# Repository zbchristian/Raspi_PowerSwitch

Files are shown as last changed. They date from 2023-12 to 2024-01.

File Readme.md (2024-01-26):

Power Switch HAT for Raspberry Pi based on Arduino Tiny
=======================================================
Per default the Raspberry Pi is powered via the USB port, but no power switch exists for a controlled shutdown.

This device connects to the GPIO and power pins of the extension port.

An Arduino Tiny (Digispark) controls the 5V supply voltage via an MOSFET switch (up to 3A).  
In addition the Arduino 
 - reads the status of the Raspberry Pi on `GPIO 27`. Pulled low while the Raspberry Pi is running, 
 - sets the shutdown request on `GPIO 17` in case the button is pressed, 
 - disconnects the 5V supply from the Raspberry Pi after a predefined timeout. This allows for a controlled shutdown and avoids a possible corruption of the SD-card. 

The device can be powered by a 5V supply, or a DC-DC converter can be added to allow the powering directly from a 12V (or higher) supply (e.g. car battery).
The Arduino is supplied by a 3.3V regulator on the board. This ensures, that the signals of the Arduino and the Raspberry Pi are compatible.

The default power button is a touch button connected via a 1MOhm resistor to Port 4 and sensed via Port 2 of the ATTINY85.
A standard button can be connected to Port 4 as well, but requires to adapt the code.

This device has been developped for the powering of a Raspberry Pi 3a used as Wireless access point (installed is [RaspAP](https://raspap.com/) ) in a very flat case. The Raspberry Pi 
is used in a Camper Van to connect to camp ground wireless networks or LTE/4G. The device is powered in this case by 12V.   

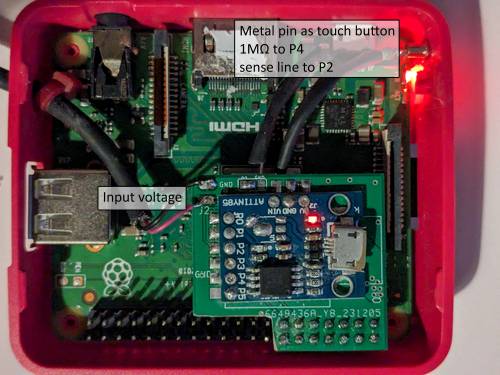
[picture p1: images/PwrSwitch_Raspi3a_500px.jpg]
Prototype Prototype of the Power Switch Raspberry Pi 3a
  
*Power switch installed on a Raspberry Pi 3a, including a touch button (metal pin)*

The power required by the device, when the Raspberry Pi is switched off, is about 20mW (ca. 1.5mA@12V).

Required Hardware Components
-------------------
 - Arduino Tiny - Digispark board. The version with the micro USB port is preferred. This allows to program the board while soldered to the PCB.
 - DC-DC converter in case the the input voltage is higher than 5V.
 - PCB and the required components (SMD components and a pin header)
 - MOSFET transistor 
   - Suitable types: FDN360P, TMS2305, DMT3098 (package: SOT-23). All allow to switch up to 2A continuously, which should still be fine for a Raspberry Pi 4.
   - For higher currents an IRF9310 (up to 16A) could be used, but this comes in a different package (SO-8) and the layout has to be changed accordingly.

Software
--------
The Arduino IDE is used for the programming of the Arduino Tiny. See the header of the program file for more details of the program flow.  
The package `CapacitiveSensor` is required, if the above mentioned touch button is used.

On the Raspberry Pi side, you need to add the following lines to `/boot/config.txt`
````
# Request shutdown by setting GPIO 17 to HIGH
dtoverlay=gpio-shutdown,gpio_pin=17,active_low=0,gpio_pull=down
# GPIO 27 flags the shutdown of the system
gpio=27=op,dl
````

Board Design
------------
Schematic and board design are available in the Autodesk EAGLE format. The library file contains the non-standard components (Arduino Tiny, DC-DC converter). Gerber files, Bill of material and placement files are available as well.

The board connects to the first 14 pins of the extension port of the Raspberry Pi via a pin header. The header connector is installed to the bottom of the board. A low profile connector 
is recommended. For the Raspberry Pi 3a in its default case, the pins had to be shortened a bit and a header with a height of only 8.6mm has been used.  

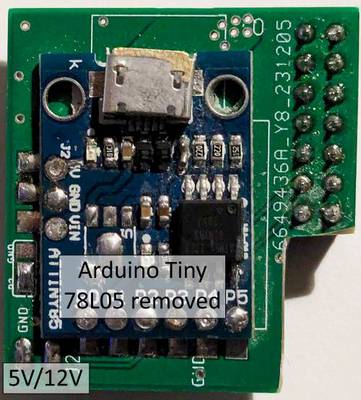
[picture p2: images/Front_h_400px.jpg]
Prototype frontside of the Raspberry Pi Power Switch
  
*Arduino Tiny soldered to the Power Switch board*

The design of the board is somewhat special, because a very flat layout is needed to fit into a standard case. 
Therefore the Arduino Tiny is soldered to large SMD pads. This is not difficult, but requires some soldering experience. It might help to solder a solid wire (0.4mm) to the through holes of the 
Arduino Tiny, bend the wires by 90° to the outside, cut to length and solder the ends of the wires to the SMD pads.  
Before soldering, add an isolating tape to the bottom of the Arduino to avoid shorts. 

On the bottom side of the board a solder jumper sets the source of the power. A closed jumper connects the input voltage from the pin header directly to the Raspberry Pi and the 
on board regulator. For higher voltages, e.g. 12V from a car battery, the jumper should be left open and a mini DC-DC converter is soldered to the SMD pads on the bottom side. The output voltage of the DC-DC converter
should be set to 5V. Again add an isolating tape to the bottom of the DC-DC converter to avoid shorts. 

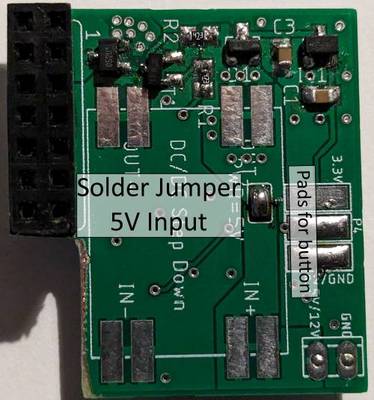
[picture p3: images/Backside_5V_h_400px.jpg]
Prototype Power switch for 5V input voltage

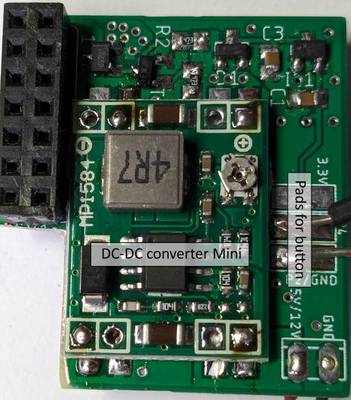
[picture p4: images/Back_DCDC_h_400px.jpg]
Prototype Power switch for 12V input voltage utilizing a DC-DC converter mini
  
*Bottom side of the Power Switch: left side for 5V input voltage with the solder jumper closed. On the right side the DC-DC converter is installed for a higher voltage*

On the bottom side you find in addition 3 solder pads to connect a button. One of the pads carries either the signal of Port 2 or ground. This can be selected by the solder jumper on the top.
 - Passive button: connect to Port 4 and the P2/GND pad and select GND with the solder jumper on the top.
 - Software based touch button: connect to P4 and P2 (select P2 with the solder jumper on top).
 - Hardware touch button: signal connected to P4. Powering by 3.3V and GND pad.

The software based touch button is implemented in the code. The other options require an adaption of the code.  

Quiescent Power Consumption
--------------------------
The Arduino Tiny will draw up to 10mA when powered by the onboard 5V regulator (78X05). This is mainly due to the quiescent current of the regulator itself , the power LED 
and the 1.5kOhm pull-up resistor connected to port 3 of the ATTINY85 (needed for the USB programming). The ATTINY85 with reduced frequency of about 1MHz
utilizes only a few hundred micro Amps. 

Reduce the required power by
 - run the ATTINY85 at a low frequency (e.g. 1MHz)
 - use an external 3.3V regulator with low quiescent current (here MCP1703). Remove the 78X05 from the board (might not be necessary).
 - either remove the power LED, or change at least the series resistor from 1kOhm to 10kOhm
 - remove the LED attached to Port 1, or increase the series resistor to 10kOhm
 - disconnect the 1.5kOhm resistor from the power rail of the ATTINY85 and connect it to the USB 5V line (USB connector side of the corresponding Schottky diode).

For a 5V powered system, this should bring the qiescent current down well below 1mA at 5V.
With the installed DC-DC converter the current stays at about 1.5mA at 12V (18mW).

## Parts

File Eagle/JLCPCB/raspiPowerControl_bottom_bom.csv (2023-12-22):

Comment | Designator | Footprint | LCSC Part #
1u | 3.3V P2/GND P4 PWR=5V C1 C3 | C0805
47k | R1 R2 | M0805
BAS40 | D1 | SOT23
BC847 | T1 | SOT23
DCDC-MINIDCDC-MINI-SMD | MP1584 | DCDC-MINI-SMD
FDN360P | Q1 | SUPER-SOT3
MCP1702/3 3.3 | IC1 | SOT23

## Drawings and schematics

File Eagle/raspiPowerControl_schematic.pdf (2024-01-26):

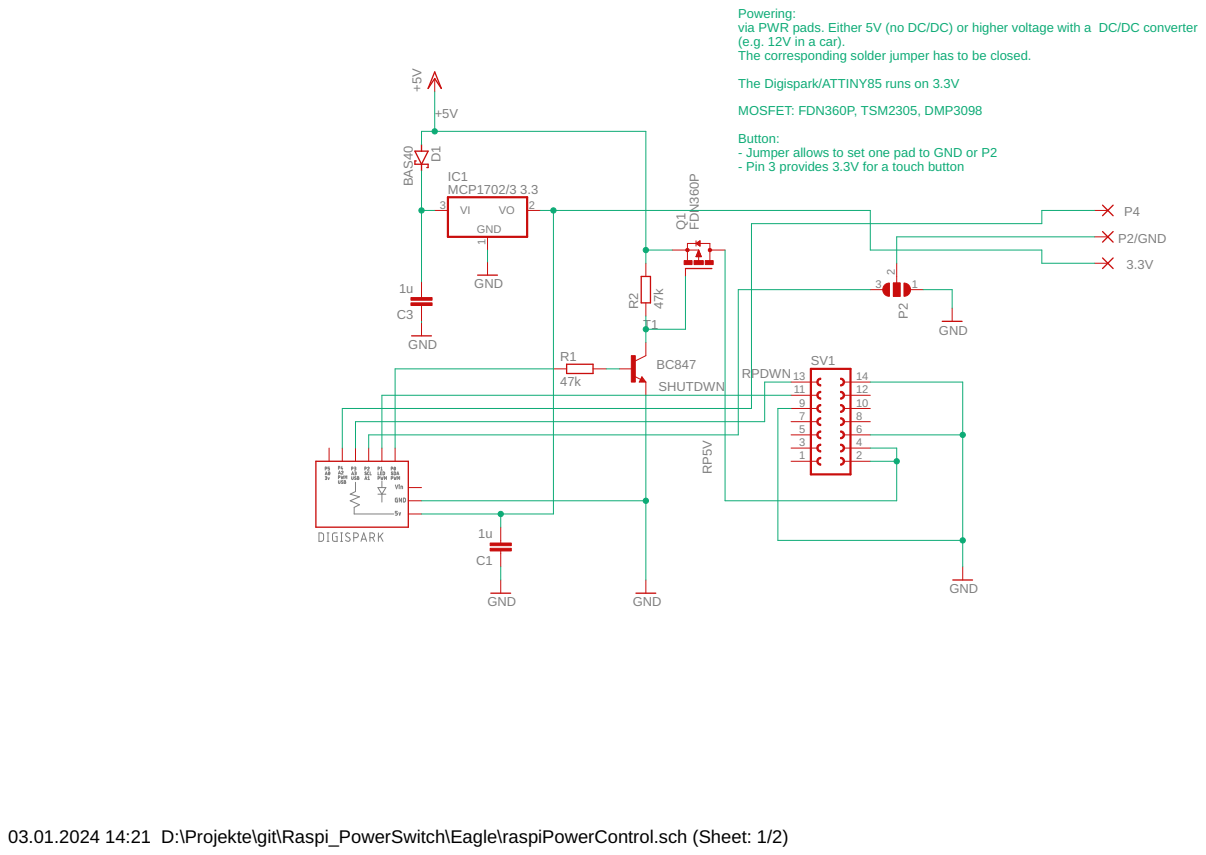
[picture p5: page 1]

Powering: via PWR pads. Either 5V (no DC/DC) or higher voltage with a DC/DC converter

(e.g. 12V in a car). The corresponding solder jumper has to be closed. The Digispark/ATTINY85 runs on 3.3V

Button: - Jumper allows to set one pad to GND or P2

- Pin 3 provides 3.3V for a touch button

03.01.2024 14:21 D:\Projekte\git\Raspi_PowerSwitch\Eagle\raspiPowerControl.sch (Sheet: 1/2)

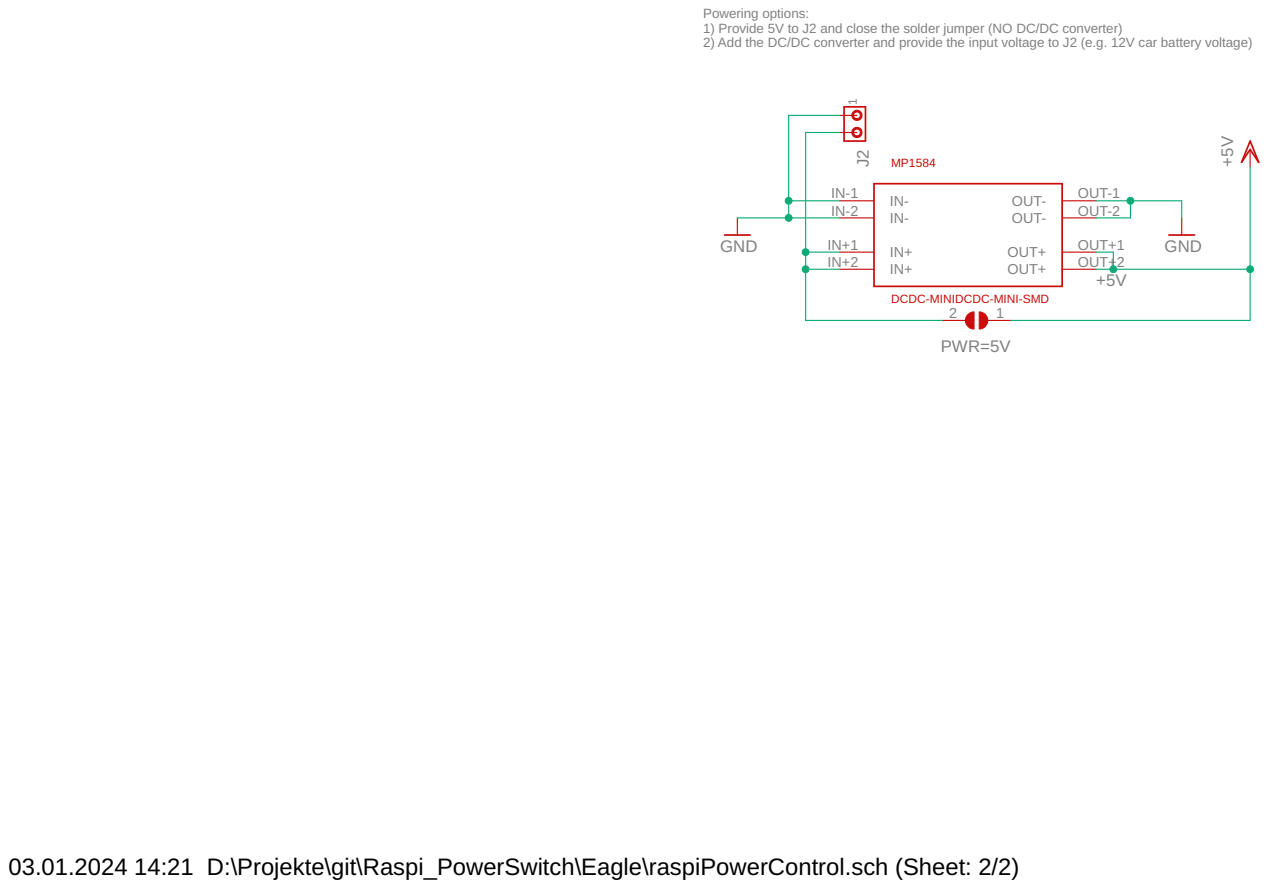
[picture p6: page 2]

Powering options: 1) Provide 5V to J2 and close the solder jumper (NO DC/DC converter) 2) Add the DC/DC converter and provide the input voltage to J2 (e.g. 12V car battery voltage)

DCDC-MINIDCDC-MINI-SMD

03.01.2024 14:21 D:\Projekte\git\Raspi_PowerSwitch\Eagle\raspiPowerControl.sch (Sheet: 2/2)

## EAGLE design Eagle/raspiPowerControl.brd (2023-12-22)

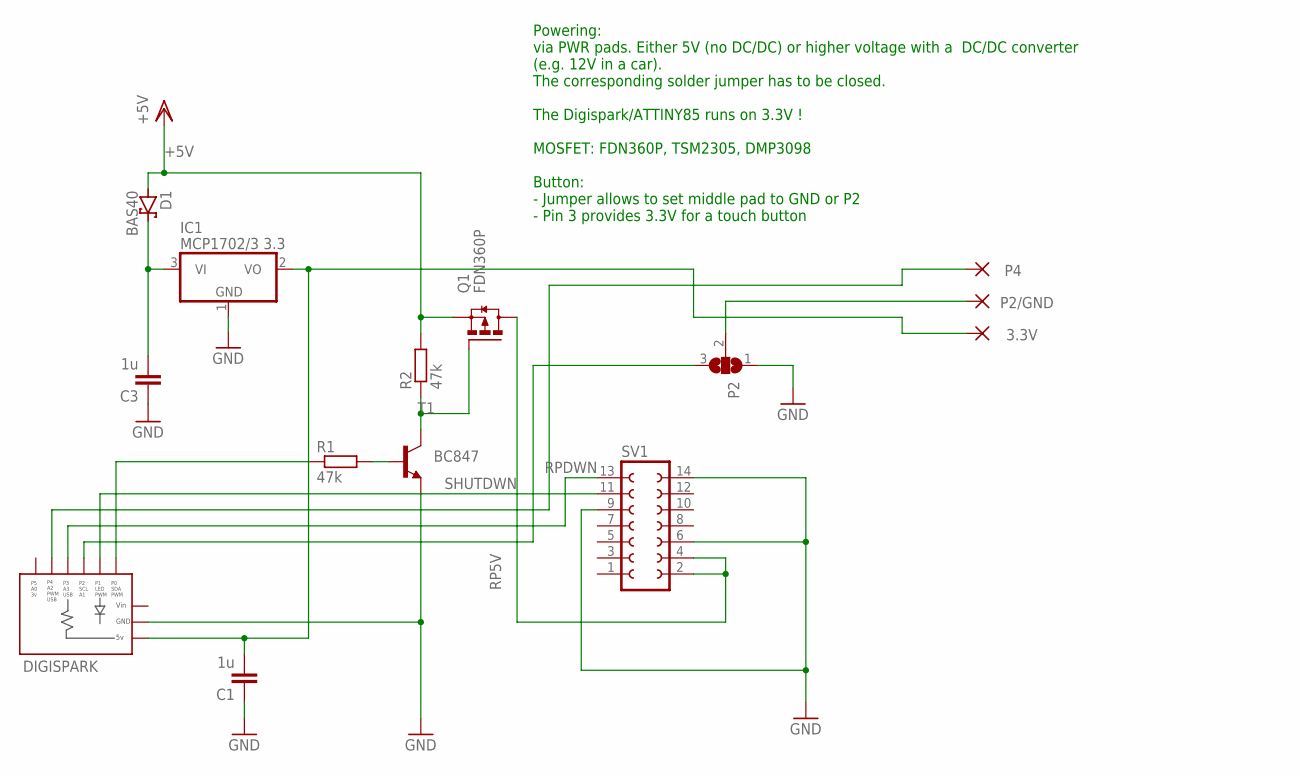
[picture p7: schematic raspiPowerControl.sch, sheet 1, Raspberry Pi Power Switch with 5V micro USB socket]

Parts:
3.3V: WIREPADSMD5-1,8; 5-1,8
C1, C3: 1u; C0805
D1: BAS40; SOT23
DIGISPARK: DIGISPARKDIGISPARK-SMD; DIGISPARK-SMD
IC1: MCP1702/3 3.3; SOT23
P2: SJ2W; SJ_2
P2/GND, P4: WIREPADSMD5-1,8; 5-1,8
Q1: FDN360P; SUPER-SOT3
R1, R2: 47k; M0805
SV1: FE07-2
T1: BC847; SOT23

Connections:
3V3: 3.3V.1, C1.2, DIGISPARK.5V, IC1.2 (VO)
+5V: D1.1 (A), Q1.2 (S), R2.2; also elsewhere on the board
BUT2: P2.2, P2/GND.1
BUT4: DIGISPARK.P4, P4.1
GND: C1.1, C3.1, DIGISPARK.GND, IC1.1 (GND), P2.1, SV1.6, SV1.9, SV1.14, T1.2 (E); also elsewhere on the board
unnamed: C3.2, D1.3 (C), IC1.3 (VI)
unnamed: Q1.1 (G), R2.1, T1.3 (C)
unnamed: R1.2, T1.1 (B)
P2: DIGISPARK.P2, P2.3
RP5V: Q1.3 (D), SV1.2, SV1.4
RPDWN: DIGISPARK.P3, SV1.13
SHUTDWN: DIGISPARK.P1, SV1.11
SWPWR: DIGISPARK.P0, R1.1
VIN: DIGISPARK.VIN

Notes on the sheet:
Powering: via PWR pads. Either 5V (no DC/DC) or higher voltage with a DC/DC converter (e.g. 12V in a car). The corresponding solder jumper has to be closed. The Digispark/ATTINY85 runs on 3.3V ! MOSFET: FDN360P, TSM2305, DMP3098 Button: - Jumper allows to set middle pad to GND or P2 - Pin 3 provide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

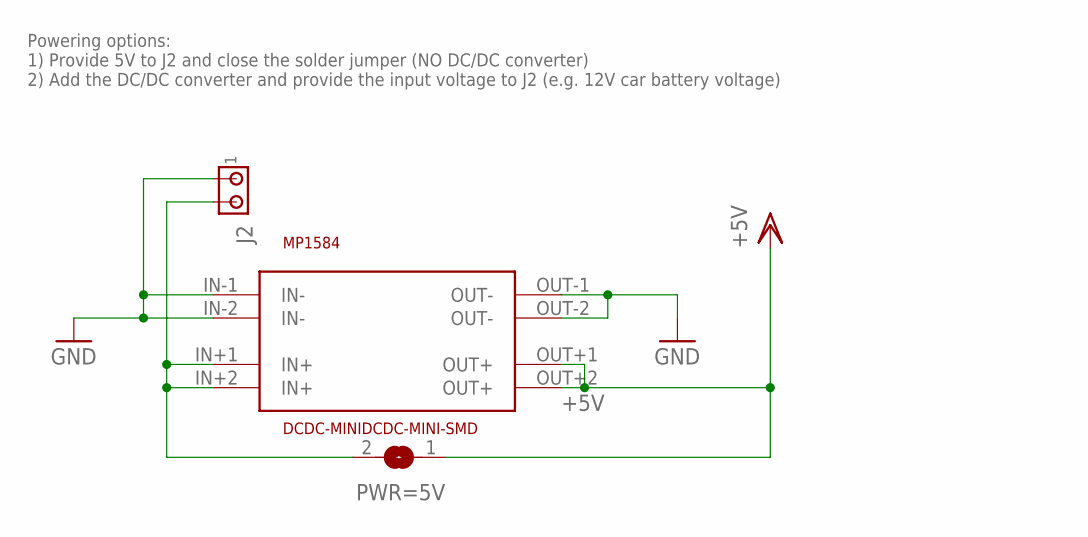
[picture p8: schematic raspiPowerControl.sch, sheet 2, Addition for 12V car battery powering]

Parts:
J2: MTA02-100; 10X02MTA
MP1584: DCDC-MINIDCDC-MINI-SMD; DCDC-MINI-SMD
PWR=5V: SJ

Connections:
+5V: MP1584.OUT+1 (OUT+), MP1584.OUT+2 (OUT+), PWR=5V.1; also elsewhere on the board
GND: J2.1, MP1584.IN-1 (IN-), MP1584.IN-2 (IN-), MP1584.OUT-1 (OUT-), MP1584.OUT-2 (OUT-); also elsewhere on the board
PWR: J2.2, MP1584.IN+1 (IN+), MP1584.IN+2 (IN+), PWR=5V.2

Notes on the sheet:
Powering options: 1) Provide 5V to J2 and close the solder jumper (NO DC/DC converter) 2) Add the DC/DC converter and provide the input voltage to J2 (e.g. 12V car battery voltage)

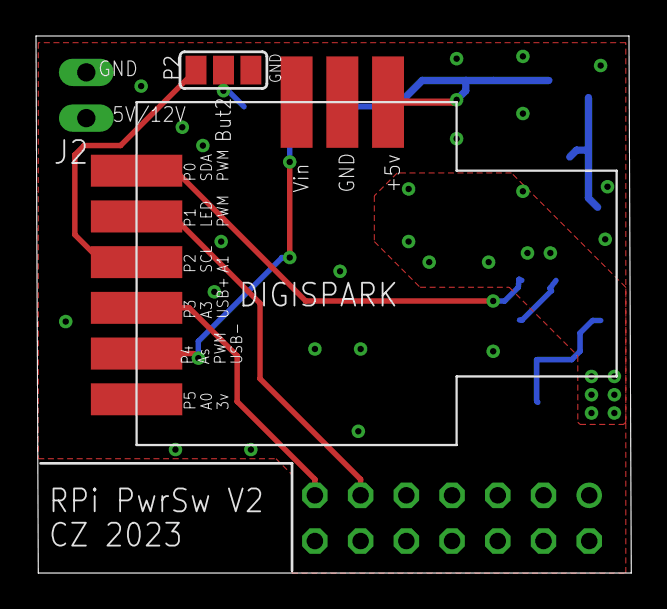
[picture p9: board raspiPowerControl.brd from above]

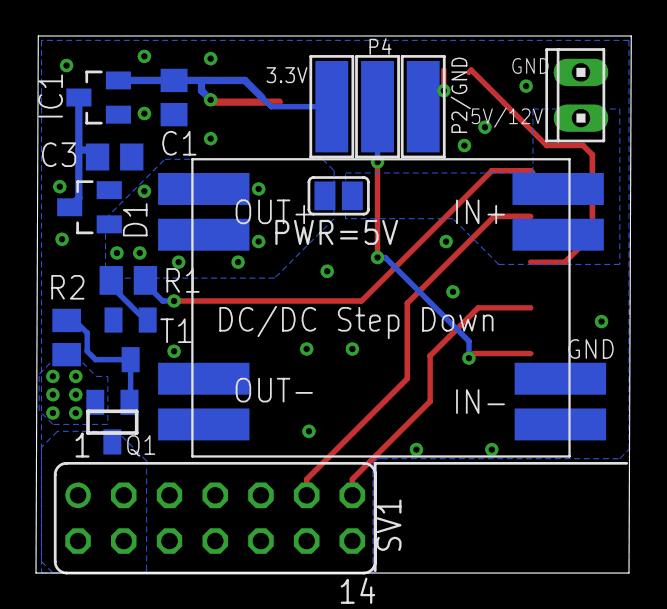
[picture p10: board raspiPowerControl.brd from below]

Board: 2 copper layers, 33.1 x 29.8 mm, 17 parts (15 on the bottom side), 14 nets.

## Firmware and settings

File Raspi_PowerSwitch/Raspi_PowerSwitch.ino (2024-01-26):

/*
  Raspberry Pi Power Switch with Digispark ATTINY85
  =================================================
  Port 0 : control  p-channel power MOSFET
  Port 1 : toggle shutdown pin of Raspi (active high) 
  Port 2 : receive pin for touch button
  Port 3 : receive shutdown info from raspi (LOW)
  Port 4 : send pin for touchbutton

  How does the code work:
  - Button (touch surface) triggers the start/shutdown of the raspberry pi
  - Power is connected/disconnected from the raspi by means of a MOSFET ( p-channel with RDS(on)<=0.1 Ohm to diconnect +5V from Raspi ) 
  - All timing is done in the Timer1 interrupt routine
  - Main loop samples the button, sets flags and acts accordingly (request shutdown/power on the raspi)

  The processor runs with a reduced clock speed to save power. Be aware, that this screws up the 
  the standard delay() function. Use delayms() instead, which uses a corrected timer.

  Required Hardware: 
    - Digispark ATTINY85 board
      o The Arduino is powered with 3.3V in order to have consistent voltage levels wrt the RPi
      o The Arduino Tiny regulator is by passed and its best to remove the 7805 
      o The power LED of the ARDUINO pulls a few mA and should be disabled or at least the resistor increased to 10k
      o The USB pull-up resistor (1.5k) should be connected to USB 5V
    - The Bootloader runs at 16.5MHz. The clock speed is reduced by means of the clock prescaler (CLK_PRESC) down to approx. 1MHz
       o Timer setup is automatically adjusted to the chosen prescale factor

  Raspberry Pi settings: 
    Configure two GPIOs in /boot/config.txt
      - Shutdown: set to HIGH and raspi will start shutdown:
          dtoverlay=gpio-shutdown,gpio_pin=17,active_low=0,gpio_pull=down  
      - Set pin to LOW when starting up. After a shutdown the GPIO is undefined. Pullup sets it to HIGH -> power can be switched off:
          gpio=27=op,dl
                        
  Required package: CapacitiveSensor

  C. Zeitnitz 2021-24
*/
#include <avr/power.h>
#include <CapacitiveSensor.h>

#define CLK_PRESC 16                // range 1-32 : automatic adjustment of CPU clock and timer setup
#define CPUClk    16.5/CLK_PRESC    // effective clock frequency in MHz - 16.5 MHz with a prescaler of 16 yields 1.03 MHz ( see setup() )

#if CLK_PRESC == 2
  #define CLOCK_DIV clock_div_2 
#elif CLK_PRESC == 4
  #define CLOCK_DIV clock_div_4 
#elif CLK_PRESC == 8
  #define CLOCK_DIV clock_div_8
#elif CLK_PRESC == 16
  #define CLOCK_DIV clock_div_16
#elif CLK_PRESC == 32
  #define CLOCK_DIV clock_div_32
#else
  #define CLOCK_DIV clock_div_1
#endif

#define MosFET    0   // switch power of Raspi on/off (HIGH/LOW in case of a p-channel FET) 
#define Shutdown  1   // inform Raspi to shutdown  
#define raspHalt  3   // Raspi sets this pin to (LOW) when running. Pulled to HIGH after shutdown 
#define CapOut    4   // connect 1-10MOhm to touch surface (small metal pin or surface)
#define CapIn     2   // connect directly to touch surface
#define CapThresh 20  // threshold to detect, that metal surface has been touched. NEEDS ADJUSTMENT! 

#define time2Boot  45  // time for the raspi to boot (sec)
#define time2Halt  15  // time for the raspi to halt after shutdown notice (sec)


CapacitiveSensor but=CapacitiveSensor(CapOut,CapIn);

volatile enum {OFF,BOOT,RUNNING,HALT} state;

volatile int  delayMillis = 0;
volatile bool isDelay = false;

// the setup function runs once when you press reset or power the board
void setup() {
  clock_prescale_set(CLOCK_DIV);  // the program should go slow - save energy
  pinMode(MosFET, OUTPUT);
  digitalWrite(MosFET, LOW);      // turn power for Raspi OFF
  pinMode(Shutdown, OUTPUT);
  digitalWrite(Shutdown, LOW);
  pinMode(raspHalt, INPUT);
  digitalWrite(raspHalt, HIGH);
  setupTimer();
  state = BOOT;
  delayms(1000);
  digitalWrite(MosFET, HIGH);   // turn power for Raspi ON -> boot
}

// check the button once per loop and act accordingly
void loop() {
  bool isON = (digitalRead(MosFET) == HIGH);
  bool isRequest = (state == RUNNING || state == OFF) && buttonActive();          // button pressed -> switch raspi ON/OFF 
  isRequest = isRequest || (state == RUNNING && digitalRead(raspHalt) == HIGH);   // raspi is shutting down on its own
  if ( isRequest ) {                            // check button/raspi state, if not in boot or halt transition
    if (isON && state == RUNNING) {             // Raspi is ON, but not yet in transition (boot or halt)
      togglePIN(Shutdown,300);                  // request raspi shutdown
      state = HALT;                             // halt process is starting
    } else if (!isON) {                         // raspi is OFF
      digitalWrite(MosFET, HIGH);               // turn power for Raspi ON
      state = BOOT;                             // boot process is starting
    }
  }
  delayms(100); // sample button every 100ms
}

bool buttonActive() {
  static int  ntouch = 0;
  long        cs = but.capacitiveSensor(50);
  bool        isAct = false;
  if (cs > CapThresh) {
      ++ntouch;
      if (ntouch>2) {
        isAct = true;
        ntouch=0;
      }
  }
  else ntouch=0;  
  return isAct;
}

volatile unsigned int delayTime = 0;
volatile unsigned int bootTime = 0;
volatile unsigned int haltTime = 0;
volatile unsigned int timeSecond = 0;
volatile bool isSecond = false;

// Timer1 interrupt
// Timing of delayms, boot and halt
// Called once every 1msec
ISR(TIMER1_COMPA_vect) 
{
  ++timeSecond;
  isSecond = (timeSecond%1000) == 0;  // 
  
  delayTime = isDelay ? delayTime+1 : 0;
  if (isDelay && (delayTime%delayMillis) == 0) isDelay = false;

  if (isSecond) {   // boot and halt timing in seconds
    haltTime = state==HALT ? haltTime+1 : 0;
    if (state==HALT && (haltTime%time2Halt) == 0 ) {
      digitalWrite(MosFET, LOW);   // turn power for Raspi OFF
      state = OFF;    
    }
    bootTime = state==BOOT ? bootTime+1 : 0;
    if ( state==BOOT && (bootTime%time2Boot) == 0 ) {
      state = RUNNING;
    }
  }
}

// Timer setup adjust automatically to the system clock (CLK_PRESC)
// setup timer1 in count and compare/match (CTC) and create interrupt once every msec
void setupTimer() {
  noInterrupts();               // disable all interrupts
  TCNT1   = 0;
  TCCR1   = 0b10000000;         // CTC1=1, COM1A1=0, COM1A0=0, last 4 bits is prescale factor
  // prescaler: 0001=1; 0010=2; 0011=4; 0100=8; 0101=16; ... (2^(cs_bits-1)) - adjust to CPU clock
  int presc = 128/CLK_PRESC;    // prescaler 128 for 16.5 MHz and just divide by prescale factor of the CPU clock
  byte cs_bits = (byte)(log(presc)/log(2)+1.5); // get bit patterns of prescale value (0.5 is added for rounding)
  TCCR1  |= cs_bits;
  TIMSK   = _BV(OCIE1A);        // enable timer compare interrupt for compare
  OCR1C   = (byte) (( (CPUClk*1000.0) / presc)+0.5); // calculate counter value for the interrupt (max 255) 
  interrupts();                 // enable all interrupts
}

void togglePIN (int pin, int msecs) {
  int pstate = digitalRead(pin);
  if(pstate == HIGH) digitalWrite(pin, LOW); 
  else digitalWrite(pin, HIGH);
  if (msecs > 0) {
    delayms(msecs);
    digitalWrite(pin, pstate);
  }
}

void delayms(int msecs) {
  delayMillis = msecs;
  isDelay = true;
  while ( isDelay );
}

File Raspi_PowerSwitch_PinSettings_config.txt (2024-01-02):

# shutdown by pulling GPIO to high level
dtoverlay=gpio-shutdown,gpio_pin=17,active_low=0,gpio_pull=down
# Set GPIO to low - after shutdown, the pin is pulled high by an external pullup (Digispark board)
gpio=27=op,dl

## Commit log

2023-09-10 Initial commit from ATTINY85 based Power switch
    [Raspi_PowerSwitch_PinSettings_config.txt]
2023-09-10 Move arduino source to sub folder
2023-09-10 Add button and change setup
    [Raspi_PowerSwitch_PinSettings_config.txt]
2023-09-11 Revert to original
    [Raspi_PowerSwitch_PinSettings_config.txt]
2023-11-04 Add Eagle design
    [raspiPowerControl.brd, raspiPowerControl.sch]
2023-11-04 Update Eagle
    [raspiPowerControl.brd, raspiPowerControl.sch]
2023-11-04 Add regulator to design
    [raspiPowerControl.brd, raspiPowerControl.sch]
2023-12-01 Add DC/DC converter to design
    [raspiPowerControl.brd, raspiPowerControl.sch]
2023-12-03 Modified layout
    [raspiPowerControl.brd, raspiPowerControl.sch]
2023-12-04 Smaller pads for button
    [raspiPowerControl.brd, raspiPowerControl.sch]
2023-12-04 Add JLC PCB and assembly files
    [raspiPowerControl.sch, raspiPowerControl_bottom_bom.csv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]
2023-12-16 Correct layout
    [raspiPowerControl.brd]
2023-12-17 Update layout
    [raspiPowerControl.brd]
2023-12-22 Update board size and touch sensor thresh
    [raspiPowerControl.brd, raspiPowerControl.sch, raspiPowerControl_bottom_bom.csv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]
2024-01-02 Add Readme.md
    [Raspi_PowerSwitch_PinSettings_config.txt]
2024-01-03 Add schematic as PDF
2024-01-03 Remove image of original prototype
2024-01-26 Correct comment in source code
    [Raspi_PowerSwitch.ino]
